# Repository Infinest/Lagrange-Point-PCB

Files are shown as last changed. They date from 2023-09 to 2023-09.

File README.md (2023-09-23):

# Lagrange Point PCB in an MMC5 cartridge
This repository contains gerber files for a PCB that allows transplanting your copy of Lagrange Point into an MMC5-type cartridge shell.
The PCB should fit into both the original shells made by Nintendo as well as these [reproduction ones](https://everdrive.me/accessories/shell-for-fami-cartridge.html).

All parts from the original PCB can be directly transferred over to the new PCB.
The only new part required is the CR2025 coin cell holder. The part number for it is `BK-6219-TR`.

The PCB needs to be ordered with a thickness of 1.2mm and the edge connector should optimally be chamfered.

# Images




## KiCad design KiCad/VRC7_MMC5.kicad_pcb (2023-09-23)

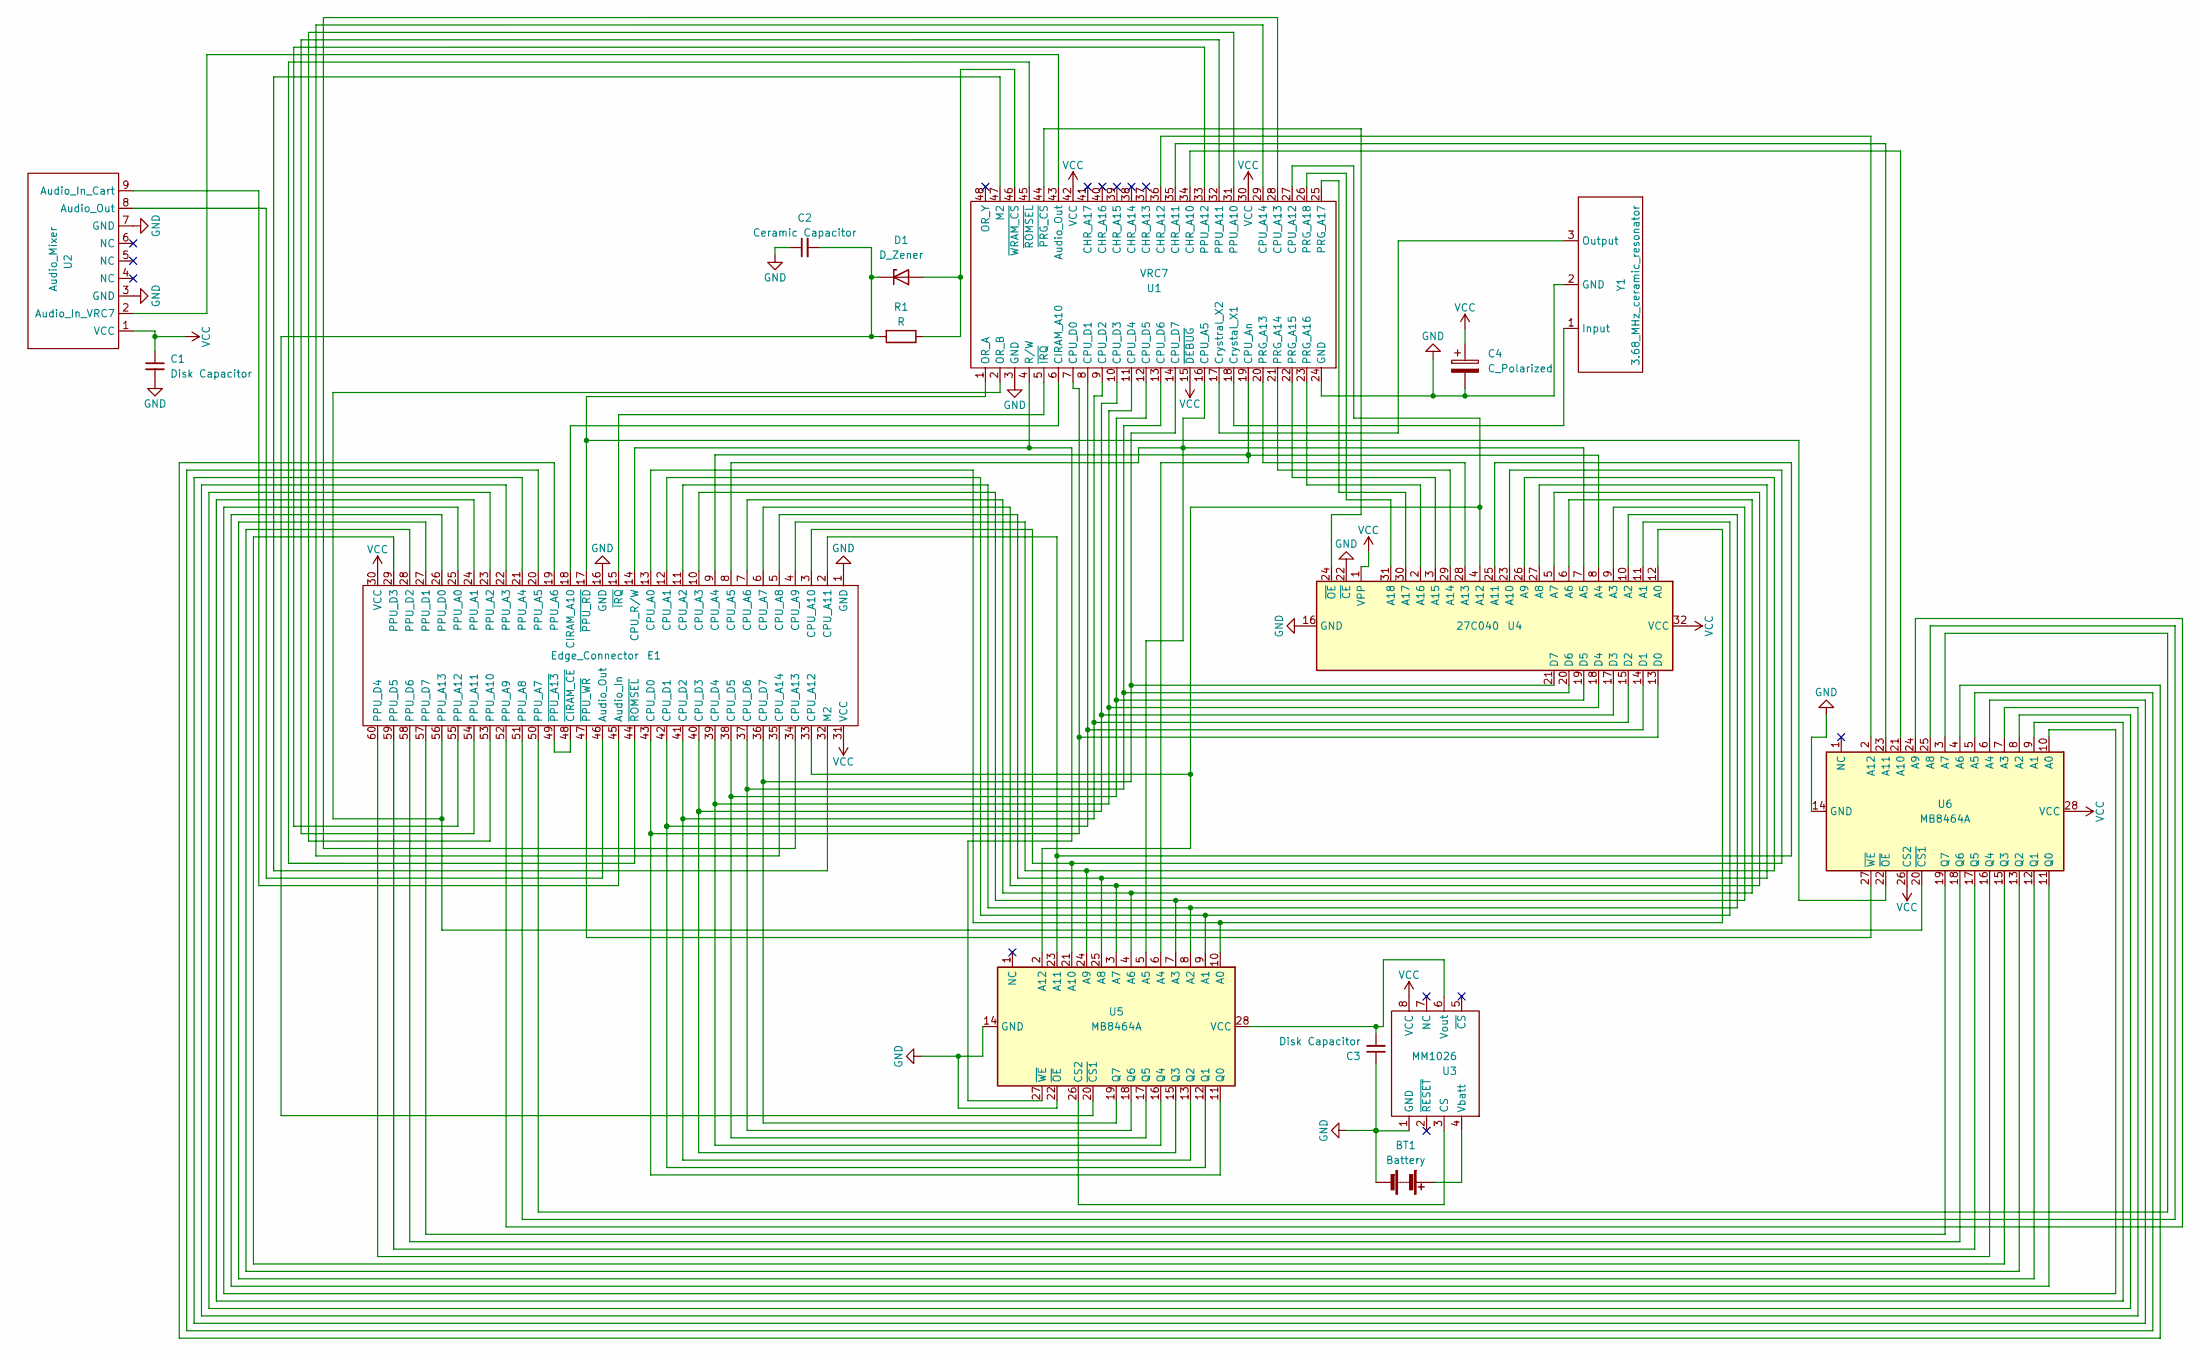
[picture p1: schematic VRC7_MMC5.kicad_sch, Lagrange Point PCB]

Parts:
BT1: Battery; BK-6219-TR
C1, C3: Disk Capacitor; C_Disc_D6.0mm_W2.5mm_P5.00mm
C2: Ceramic Capacitor; C_Disc_D3.8mm_W2.6mm_P2.50mm
C4: C_Polarized; C_Radial_D6.3mm_H7.0mm_P2.50mm
D1: D_Zener; D_DO-34_SOD68_P10.16mm_Horizontal
E1: Edge_Connector; Famicom Edge Connector
R1: R; R_Axial_DIN0207_L6.3mm_D2.5mm_P10.16mm_Horizontal
U1: VRC7; DIP-48_W15.24mm_LongPads
U2: Audio_Mixer; Audio Mixer VRC7
U3: MM1026; DIP-8_W7.62mm_LongPads
U4: 27C040; DIP-32_W15.24mm_LongPads
U5, U6: MB8464A; DIP-28_W15.24mm_LongPads
Y1: 3.68_MHz_ceramic_resonator; Resonator-3Pin_W7.0mm_H2.5mm

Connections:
GND: BT1.2 (-), C1.2, C2.1, C3.1, C4.2, E1.1 (GND), E1.16 (GND), U1.3 (GND), U1.24 (GND), U2.3 (GND), U2.7 (GND), U3.1 (GND), U4.16 (GND), U4.22 (~CE), U5.14 (GND), U5.22 (~OE), U6.14 (GND), Y1.2 (GND)
unnamed: BT1.1 (+), U3.4 (Vbatt)
unnamed: C2.2, D1.1 (K), R1.2, U5.20 (~CS1)
unnamed: C3.2, U3.6 (Vout), U5.28 (VCC)
unnamed: D1.2 (A), R1.1, U1.46 (~WRAM_CS)
unnamed: E1.2 (CPU_A11), U4.25 (A11), U5.23 (A11)
unnamed: E1.3 (CPU_A10), U4.23 (A10), U5.21 (A10)
unnamed: E1.4 (CPU_A9), U4.26 (A9), U5.24 (A9)
unnamed: E1.5 (CPU_A8), U4.27 (A8), U5.25 (A8)
unnamed: E1.6 (CPU_A7), U4.5 (A7), U5.3 (A7)
unnamed: E1.7 (CPU_A6), U4.6 (A6), U5.4 (A6)
unnamed: E1.8 (CPU_A5), U1.16 (CPU_A5), U4.7 (A5), U5.5 (A5)
unnamed: E1.9 (CPU_A4), U1.19 (CPU_An), U4.8 (A4), U5.6 (A4)
unnamed: E1.10 (CPU_A3), U4.9 (A3), U5.7 (A3)
unnamed: E1.11 (CPU_A2), U4.10 (A2), U5.8 (A2)
unnamed: E1.12 (CPU_A1), U4.11 (A1), U5.9 (A1)
unnamed: E1.13 (CPU_A0), U4.12 (A0), U5.10 (A0)
unnamed: E1.14 (CPU_R/W), U1.4 (R/W), U5.27 (~WE)
unnamed: E1.15 (~IRQ), U1.5 (~IRQ)
unnamed: E1.17 (~PPU_RD), U1.1 (OR_A), U6.22 (~OE)
unnamed: E1.18 (CIRAM_A10), U1.6 (CIRAM_A10)
unnamed: E1.19 (PPU_A6), U6.4 (A6)
unnamed: E1.20 (PPU_A5), U6.5 (A5)
unnamed: E1.21 (PPU_A4), U6.6 (A4)
unnamed: E1.22 (PPU_A3), U6.7 (A3)
unnamed: E1.23 (PPU_A2), U6.8 (A2)
unnamed: E1.24 (PPU_A1), U6.9 (A1)
unnamed: E1.25 (PPU_A0), U6.10 (A0)
unnamed: E1.26 (PPU_D0), U6.11 (Q0)
unnamed: E1.27 (PPU_D1), U6.12 (Q1)
unnamed: E1.28 (PPU_D2), U6.13 (Q2)
unnamed: E1.29 (PPU_D3), U6.15 (Q3)
unnamed: E1.32 (M2), U1.47 (M2)
unnamed: E1.33 (CPU_A12), U1.27 (CPU_A12), U4.4 (A12), U5.2 (A12)
unnamed: E1.34 (CPU_A13), U1.28 (CPU_A13)
unnamed: E1.35 (CPU_A14), U1.29 (CPU_A14)
unnamed: E1.36 (CPU_D7), U1.14 (CPU_D7), U4.21 (D7), U5.19 (Q7)
unnamed: E1.37 (CPU_D6), U1.13 (CPU_D6), U4.20 (D6), U5.18 (Q6)
unnamed: E1.38 (CPU_D5), U1.12 (CPU_D5), U4.19 (D5), U5.17 (Q5)
unnamed: E1.39 (CPU_D4), U1.11 (CPU_D4), U4.18 (D4), U5.16 (Q4)
unnamed: E1.40 (CPU_D3), U1.10 (CPU_D3), U4.17 (D3), U5.15 (Q3)
unnamed: E1.41 (CPU_D2), U1.9 (CPU_D2), U4.15 (D2), U5.13 (Q2)
unnamed: E1.42 (CPU_D1), U1.8 (CPU_D1), U4.14 (D1), U5.12 (Q1)
unnamed: E1.43 (CPU_D0), U1.7 (CPU_D0), U4.13 (D0), U5.11 (Q0)
unnamed: E1.44 (~ROMSEL), U1.45 (~ROMSEL)
unnamed: E1.45 (Audio_In), U2.9 (Audio_In_Cart)
unnamed: E1.46 (Audio_Out), U2.8 (Audio_Out)
unnamed: E1.47 (~PPU_WR), U6.27 (~WE)
unnamed: E1.48 (~CIRAM_CE), E1.49 (~PPU_A13)
unnamed: E1.50 (PPU_A7), U6.3 (A7)
unnamed: E1.51 (PPU_A8), U6.25 (A8)
unnamed: E1.52 (PPU_A9), U6.24 (A9)
unnamed: E1.53 (PPU_A10), U1.31 (PPU_A10)
unnamed: E1.54 (PPU_A11), U1.32 (PPU_A11)
unnamed: E1.55 (PPU_A12), U1.33 (PPU_A12)
unnamed: E1.56 (PPU_A13), U1.2 (OR_B), U6.20 (~CS1)
unnamed: E1.57 (PPU_D7), U6.19 (Q7)
unnamed: E1.58 (PPU_D6), U6.18 (Q6)
unnamed: E1.59 (PPU_D5), U6.17 (Q5)
unnamed: E1.60 (PPU_D4), U6.16 (Q4)
unnamed: U1.17 (Crystral_X2), Y1.3 (Output)
unnamed: U1.18 (Crystal_X1), Y1.1 (Input)
unnamed: U1.20 (PRG_A13), U4.28 (A13)
unnamed: U1.21 (PRG_A14), U4.29 (A14)
unnamed: U1.22 (PRG_A15), U4.3 (A15)
unnamed: U1.23 (PRG_A16), U4.2 (A16)
unnamed: U1.25 (PRG_A17), U4.30 (A17)
unnamed: U1.26 (PRG_A18), U4.31 (A18)
unnamed: U1.34 (CHR_A10), U6.21 (A10)
unnamed: U1.35 (CHR_A11), U6.23 (A11)
unnamed: U1.36 (CHR_A12), U6.2 (A12)
unnamed: U1.43 (Audio_Out), U2.2 (Audio_In_VRC7)
unnamed: U1.44 (~PRG_CS), U4.24 (~OE)
unnamed: U3.3 (CS), U5.26 (CS2)
VCC: C1.1, C4.1, E1.30 (VCC), E1.31 (VCC), U1.15 (~DEBUG), U1.30 (VCC), U1.42 (VCC), U2.1 (VCC), U3.8 (VCC), U4.1 (VPP), U4.32 (VCC), U6.26 (CS2), U6.28 (VCC)

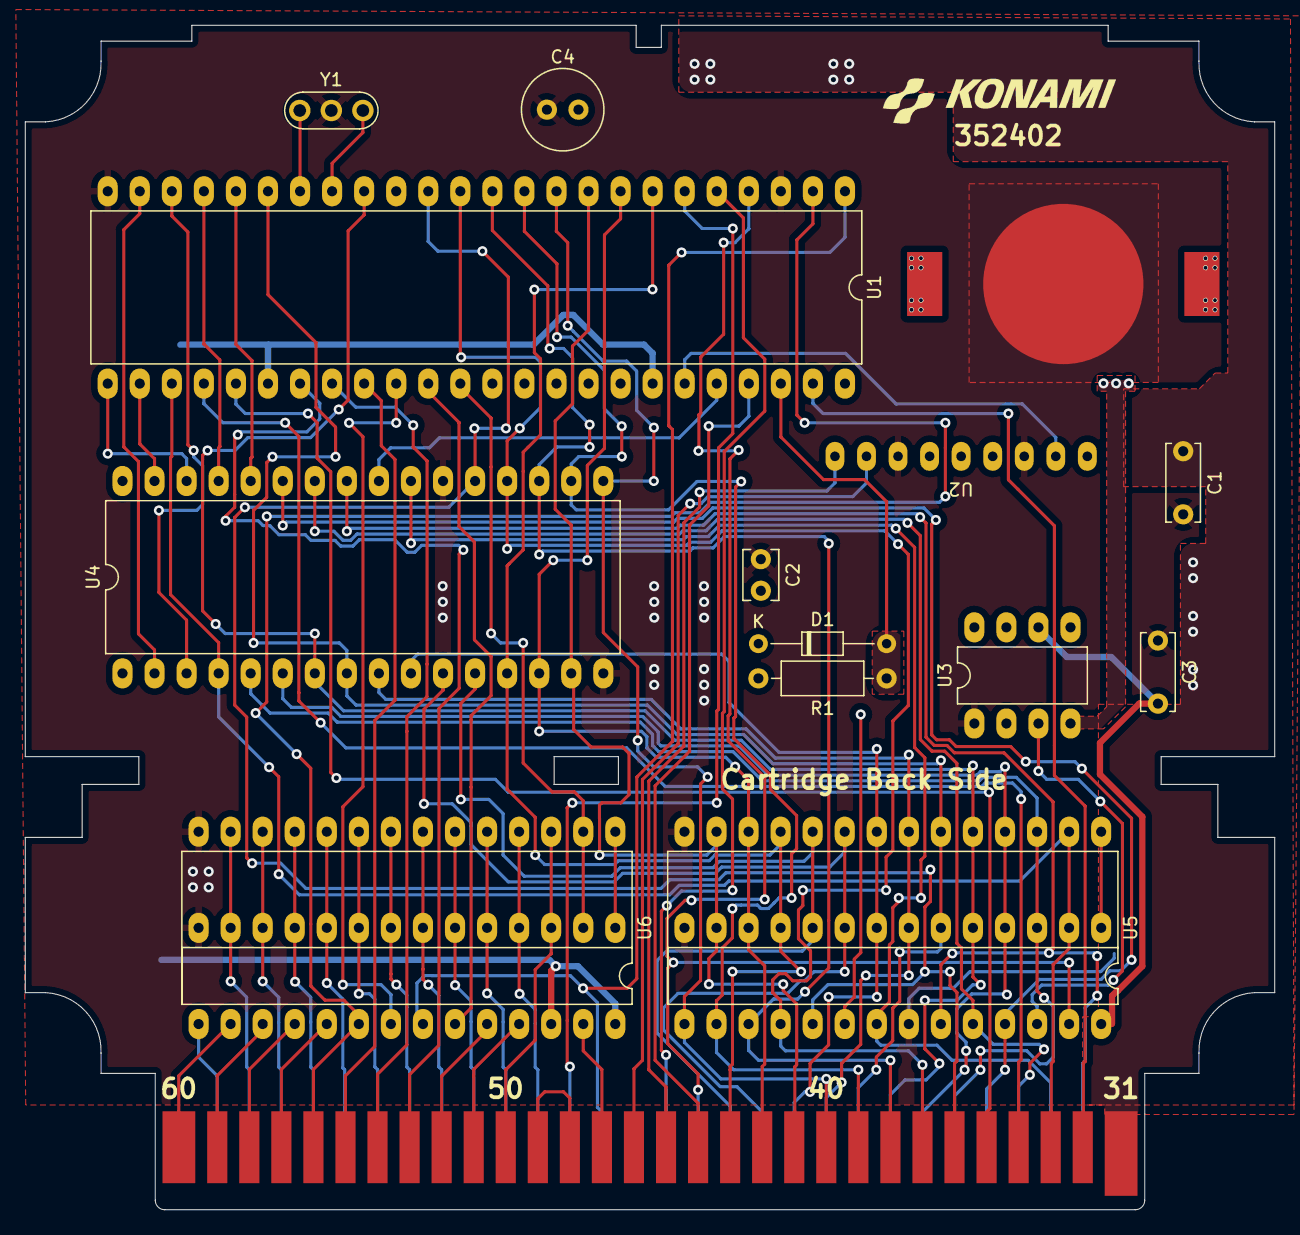
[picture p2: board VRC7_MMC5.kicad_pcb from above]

Board: 2 copper layers, 99.0 x 93.8 mm, 15 parts (0 on the bottom side), 75 nets.

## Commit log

2023-05-03 Add gerber files
2023-09-23 Add KiCad project folder
    [VRC7_MMC5.kicad_pcb, VRC7_MMC5.kicad_sch]
2023-09-23 Rename folder
    [VRC7_MMC5.kicad_pcb, VRC7_MMC5.kicad_sch]
